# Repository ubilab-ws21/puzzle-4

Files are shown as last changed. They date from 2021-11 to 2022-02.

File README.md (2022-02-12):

# Team 4: Picture Puzzle #
We are building a puzzle in the Ubiquitous Computing Lab (UCL) aka Escape Room in WS21/22.
The Firmware folder contains all the Software code used for this project. 
In the Sequences folder are the created sequences as .mp4 and .pdf and also a solution file.
The Hardware folder contains most of the manuals and guides for the used hardware parts in our riddle for example the pin-assignment for the ESP32.

## Content #
* [Puzzle in Storyline](#1)
* [How the puzzle works](#2)
* [MQTT Documentation](#3)
* [Hardware](#4)
* [Project Timeline](#5)

## Puzzle in Storyline 
The players face a horrible situation because a solar storm happens while they visit a power supplier. This results in shutting down all electricity which is very dangerous because we are in the year 2050 and the blind trust in the technology is so big that this shutdown could be an apocalyptic scenario.
So the group needs to get access to the lab and server room and reboot the server with the control-software. In this way they can save our city by starting the electricity. 

Our picture puzzle starts after the team got acces to the lab and server room and solved the knock knock riddle to activate the server. So the server is working now but still secured by a code. To solve this puzzle the group needs to work as a team and under time pressure.
To stop unauthorized access the code can only be solved by people who work in the lab and know the enviroment. Another security mechanism is the need of more than one person similar to the two-man-mechanism from nuclear codes. One person always needs to stand at the server and press a button there while the others can walk freely in the room. The group needs to walk around and communicate with each other to solve it in time. 
After finding the solution and typing it into the server, they get access and the server reboots which results in saving our world. 

Accordingly the Escape Room is solved. 

## How the puzzle works
The puzzle starts by showing a text that the red button on the server needs to be pressed the whole time. After that a video sequence of picture cutouts included in a mathematical equation is shown. Simultanously there starts a text-to-speach which says that the server is locked and a password needs to be entered. The players need to find the corresponding picture from the cutout and take the number below into the equation to get one digit of the solution. There is a total of four equations with cutouts and therefore consists the solution of four digits.
After showing the four equations the sequence restarts as long as a predefined time. This predefined time depends on the amount of players. Two players get more time than four. Afterwards there will be a completely new sequence with other cutouts in other mathematical equations. Such a equation with a given cutout can be seen in the following picture:

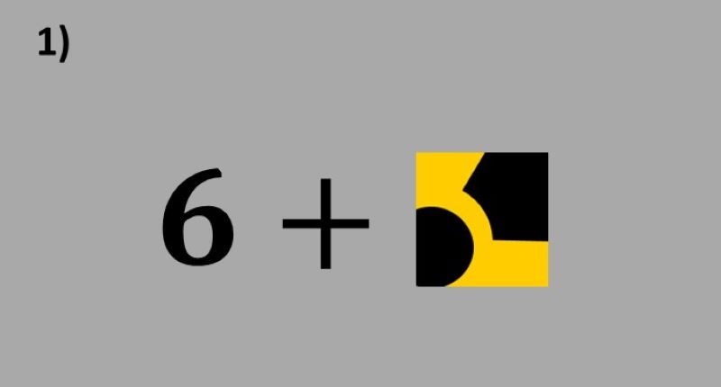
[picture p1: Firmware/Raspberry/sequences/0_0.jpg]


When seeing this on the server display the players should recognize this picture cutout from the rooms they played in before. Because in the entrance room and the lab room are many warning signs at the walls. An overview of all the warning signs can be seen in the next picture:



We placed them in pairs of two pictures at different walls in different rooms so the players have to use the whole space. Additionally we force the group to communicate with each other and benefit teamwork.
Under each picture will be a seven segment display and a button. The display only shows a number when the related button is pressed. To stop one person to stand in the middle of the room and look at the numbers under each picture. This can be seen in the next picture:

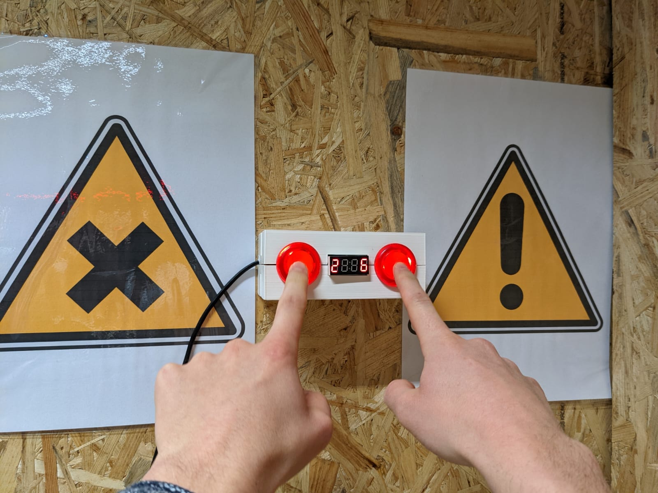
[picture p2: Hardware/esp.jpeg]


By finding the four pictures and the resulting four numbers and putting them in the equations the group should get a four digit code which they need to type in the server with a given numpad.
Overall does every picture pair consists of one ESP32, two buttons and four seven segment displays. The server consists of the numpad, Raspberry Pi and a display. Additionally there is an ESP32 with a seven-segment-display which represents the timer and a red button. The numpad, timer and red button can be seen in the next picture:

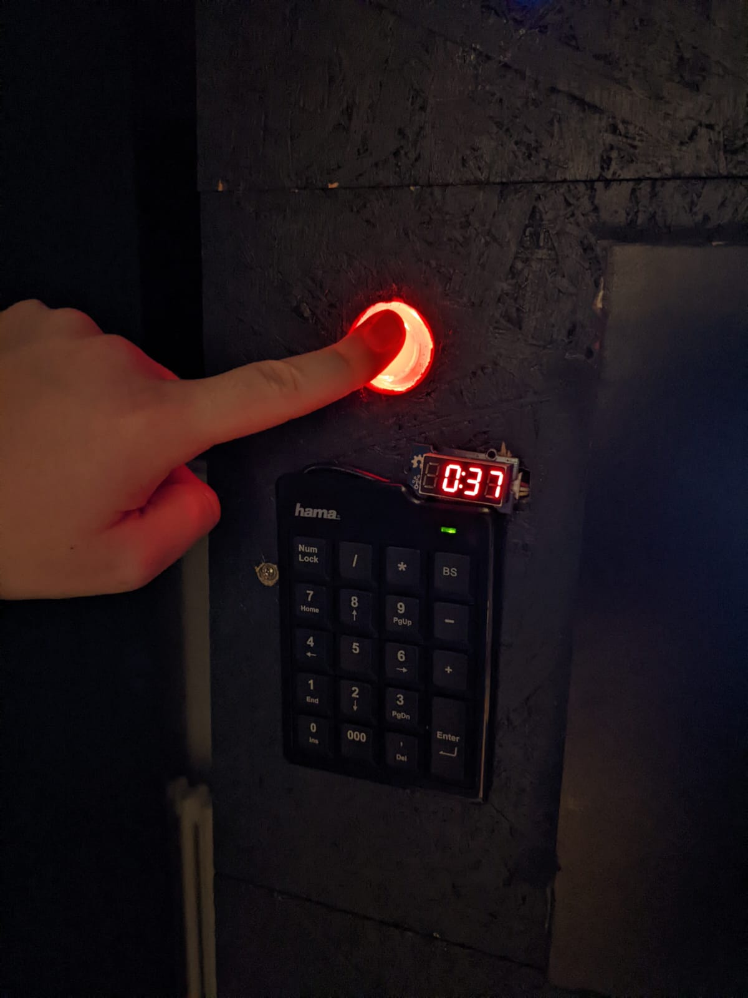
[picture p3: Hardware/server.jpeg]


All the ESP32 and the Raspberry Pi communicate via MQTT. Further MQTT informations can be found in the [MQTT Documentation](#3) or the [MQTT overview](https://github.com/ubilab-ws21/puzzle-4/tree/main/MQTT "MQTT overview").
At the beginning the Raspberry Pi is sending a retained message to the operator and AR hint system. After that it is waiting for the start message from the operator. When receiving this message the Raspi will send the starting sequence to the ESPs and starts with the first sequence. The ESP32 will power the buttons so they will light up and show the corresponding first number on the seven segment display when pressed. 
After some time has passed and the puzzle is not solved or the players enter a wrong code or the red button on the server dropped the Raspberry Pi sends a MQTT message at the text to speech to play a text to speech: "new sequence". So the players know that sequence has changed. Also the ESP32 receive a MQTT message from the Raspi that they need to change the numbers, a new sequence is shown on the display and the timer restarts. 
Therefore all numbers are saved in an array.

The following flow chart shows the overall course of events of our puzzle.

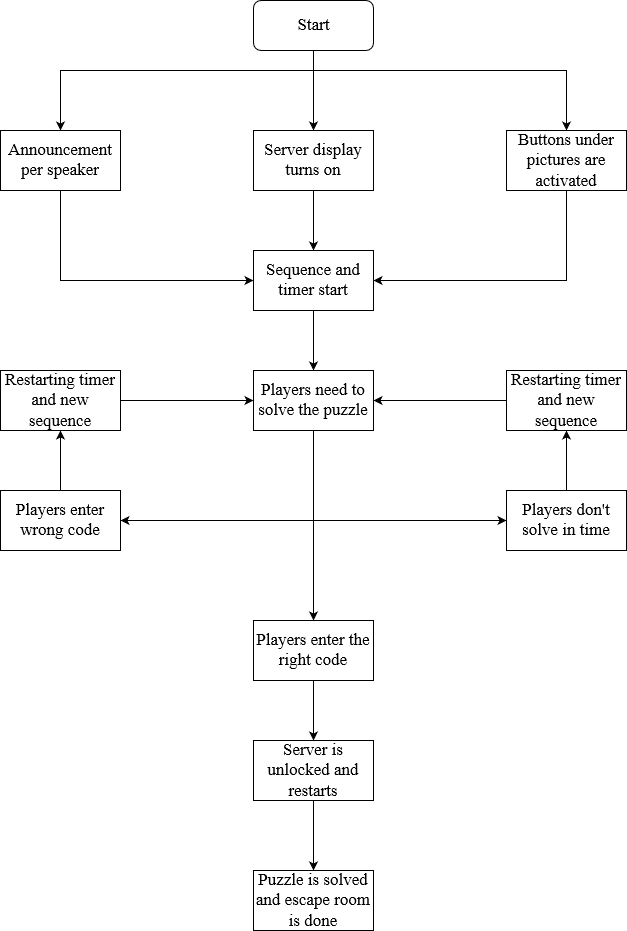
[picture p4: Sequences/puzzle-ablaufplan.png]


## MQTT Documentation 
In our communication design we distinguish between internal and external communication. The Raspi does everything external with the operator and hint system. The Raspi is sending and receiving informations from and to the individual ESPs. So all ESPs communicate internally with each other. A better overview for our MQTT communication and structure can be seen in the MQTT folder. There are also tables with the used topics and messages. 
[MQTT overview](https://github.com/ubilab-ws21/puzzle-4/tree/main/MQTT "MQTT overview")

## Hardware 
All documents and manuals needed to reconstruct this puzzle are in the "Hardware" folder.
The following picture gives on overview how the used hardware inside of the created case looks like:

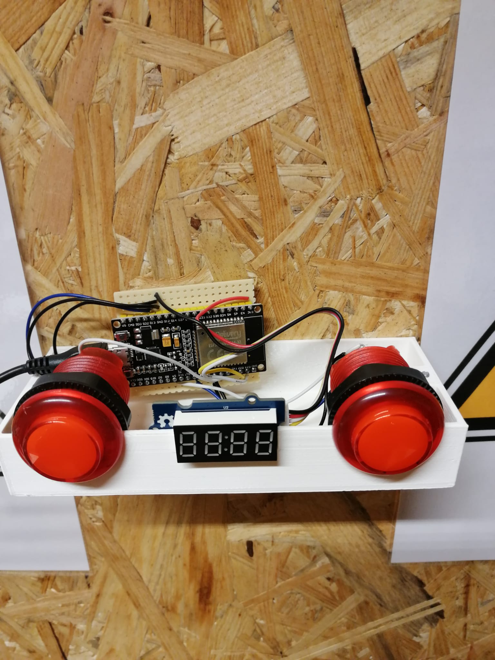
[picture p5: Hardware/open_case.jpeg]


## Project Timeline 
- [x] Concept finding for puzzle
- [x] Creating a BOM
- [x] Programming and testing OTA and MQTT with ESP32
- [x] Preparing warning signs and creating cutout sequences
- [x] First rough test run in the Escape room
- [x] Assembly of hardware for the under pictures buttons & 7-segment-displays
- [x] First software prototype for controlling the 7-segment-displays with arcade buttons
- [x] Soldering all parts together
- [x] Designing a 3D case in SolidWorks
- [x] Assembly of electronic with first case
- [x] Creating the GUI and Software for the Raspberry
- [x] Edit the 3D case and print the missing parts
- [x] Conception and creation of the timer 
- [x] Testing the network communication between the systems in the escape room
- [x] Assembly of the missing parts
- [x] Designing the final sequences for the riddle
- [x] Printing and foil-coating the pictures
- [x] Mount all parts in the room
- [x] Added progress bar after finishing the riddle
- [x] Implement extra button as dead-man switch
- [x] Fixed issues after integration run
- [x] Make use of AR hint system
- [x] Coordinate MQTT with operator
- [x] Provide power supply for all of them
- [x] Last testing and bug fixing
- [x] Finish documentation
- [x] Final run
- [x] very last bug fixes
- [x] Final run 2.0

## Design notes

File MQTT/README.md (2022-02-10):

### MQTT topics
| Topic | Description | Subscriber | Publisher |
| :--:	| :---: | :---: | :---:|
| 4/gamecontrol | general communication | operator, Raspi | operator, Raspi |
| op/gamecontrol | for the player amount | Raspi | operator |
| puzzle4/esp | messages for all 5 ESPs | ESP1-4 + Timer | Raspi |
| puzzle4/esp/timer | messages for Timer ESP | Timer ESP | Raspi |
| puzzle4/esp/timer/players | messages for Timer ESP | Timer ESP | Raspi |
| puzzle4/esp/sequence | messages for picture ESPs | ESP1-4 | Raspi |
| game/puzzle4 | AR hint system | Raspi, AR System | Raspi, AR System |

### MQTT commands
The following messages can be used to start or stop puzzle 4. These are send from the operator to the Raspi in "4/gamecontrol":
| method  | state  | data | | description |
|---|---|---|---|---|
| trigger | on | | | Starts the puzzle. |
| trigger | off | | | Restarts the puzzle and waits for a new 'trigger on'. |
| trigger | off | skipped | | Puzzle switches immediately into the solved state and waits for a 'trigger off' to restart. | 

The following messages are sent by the Raspi in "4/gamecontrol" to report the current status:

| method | state | data | | description |
|---|---|---|---|---|
| status | inactive | | | The Raspi has finished it's initialization and waits for a 'trigger on'. |
| status | active | | | The Raspi has received a 'trigger on' message and starts the puzzle. |
| status | solved | | | The picture puzzle is solved and waits for a 'trigger off'. |

### Chart of our MQTT communication


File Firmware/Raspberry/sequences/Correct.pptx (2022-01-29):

## Press and hold red button to start server boot process.

## Safety meassure: Keep pressing the button during bootup

## Server is starting up. Please enter Code on the next screen.

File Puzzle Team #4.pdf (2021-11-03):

# Puzzle Team #4

## Some puzzle ideas

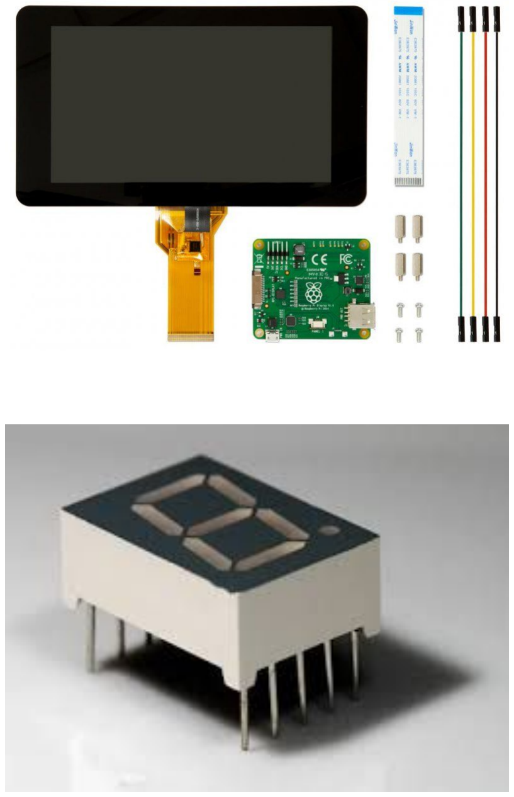
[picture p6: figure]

## Puzzle Idea #1: Warning-Sign-Puzzle

- General idea: Coop-puzzle
- One terminal in the room
- ideally in the server room: separate players → communication is needed
- 8-10 pictures distributed in both rooms
- maybe thematically matching warning signs
- under each picture is a 7-segment-display
- terminal shows parts of the pictures and an mathematical computation
- players have to search for the matching signs and solve the puzzle
- resulting in a 4-6 digit password to continue the escape room
- players are working under a time limit (e.g. 60-90s)

## Puzzle Idea #1: Warning-Sign-Puzzle

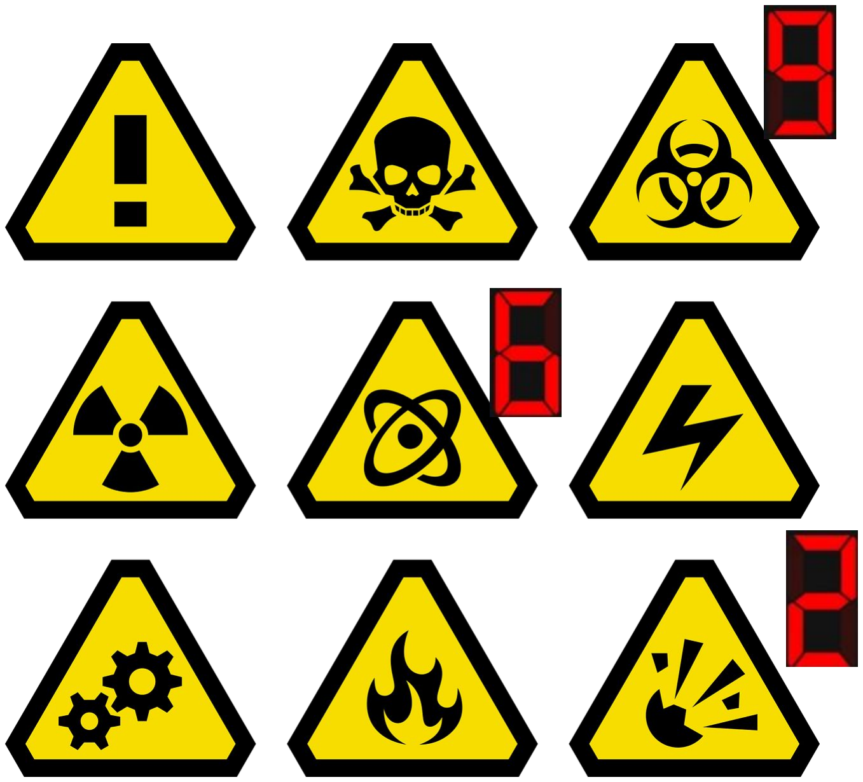
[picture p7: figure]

- Possible Sequence:
+3 | -2 | +1
- Resulting password: 5-7-7
- Players should fail on first attempt
- puzzle resets (numbers and sequence change)
- slowly learn the rules of the puzzle
- Time limit and difficulty in general are dependant on the number of players

## Puzzle Idea #2: Beamer

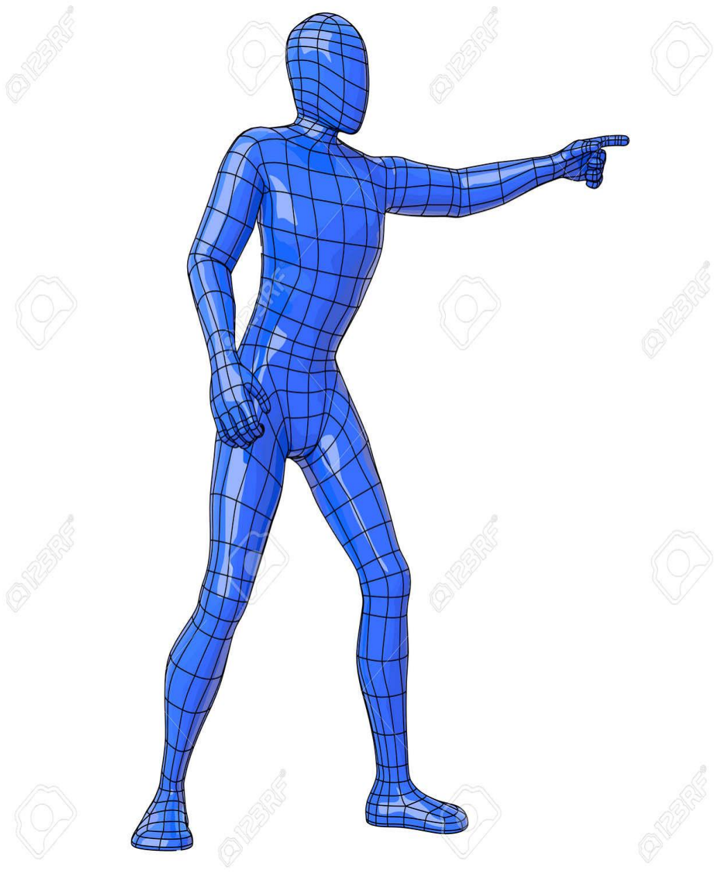
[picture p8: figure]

- after solving a puzzle, a beamer turns on and shows a blue screen on a wall
- there are multiple numbers on the wall but which number is the right one?
- players find one or more objects to put in front of the beamer
- fingers of the objects point to e.g. numbers on the wall
- players have to place the objects in an determined order
- resulting code opens something

## Puzzle Idea #3: Checkerboard

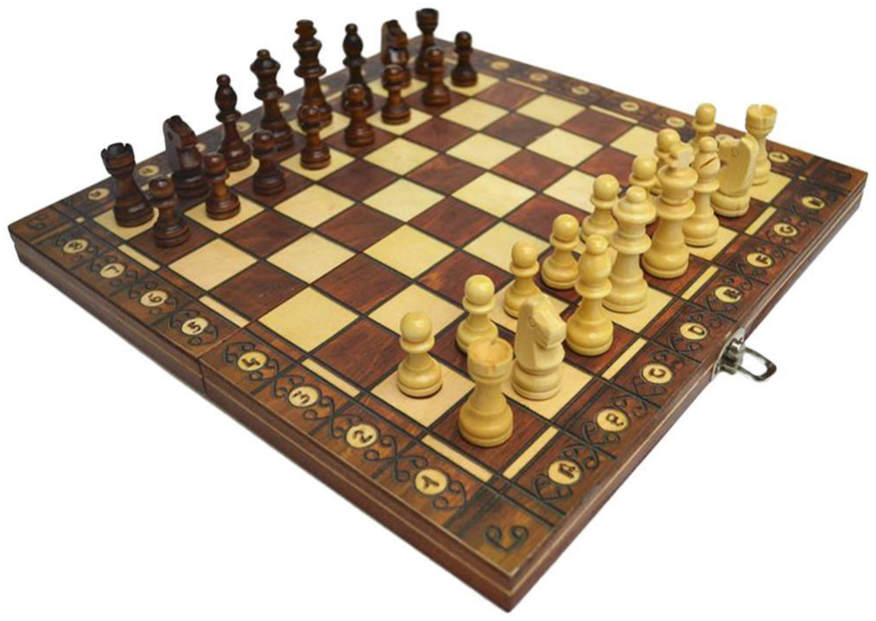
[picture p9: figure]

- players find a checkerboard with some figures standing on it
- can be glued to the board
- find another figure
- have to figure out the position that wins the game
- the figure has a small RFID chip in it
- by placing it on the correct position the next puzzle gets started
- not everyone knows the rules to chess
- players could find the moveset of the figures on a poster in the room
- or different game

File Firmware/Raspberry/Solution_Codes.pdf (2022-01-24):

## Escape Room Numbers

Sequenz | 0 | 1 | 2 | 3 | 4 | 5 | 6 | 7 | 8 | 9
Kreuz: | | 3 | | 6 | | 5 | | 7 | | 7
Ausrufezeichen: 3 | 6 | 3 | 7
Schneeflocke: | 4 | 5 | 2 | 6 | 4
Feuer: | 7 | 9 | 8 | 2 | 4 | 4
Blitz: | 3 | 2 | 1 | 2 | 5
Radioaktiv: | 1 | 4 | 9 | 8 | 7
Funk: | 2 | 1 | 3 | 8 | 6
Magnet: | 2 | 2 | 3 | 1 | 5

Sequenz0: 7 – 5 – 4 – 8

Sequenz1: 5 – 8 – 4 – 9

Sequenz2: 9 – 8 – 3 – 4

Sequenz3: 3 – 1 – 7 – 0

Sequenz4: 7 – 4 – 1 – 3

Sequenz5: 4 – 4 – 6 – 9

Sequenz6: 5 – 7 – 1 – 6

Sequenz7: 4 – 8 – 2 – 7

Sequenz8: 5 – 3 – 9 – 2

Sequenz9: 9 – 2 – 6 – 3

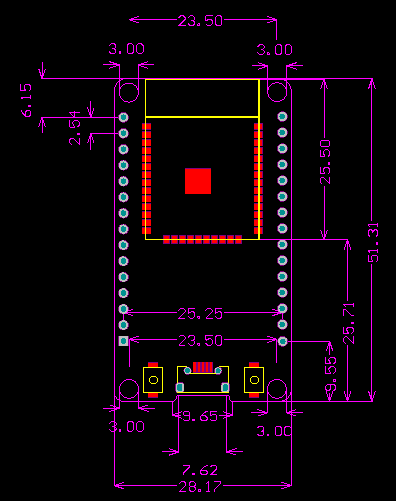
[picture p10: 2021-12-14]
Hardware/Case/SBC-NodeMCU-ESP32_dimensions.png

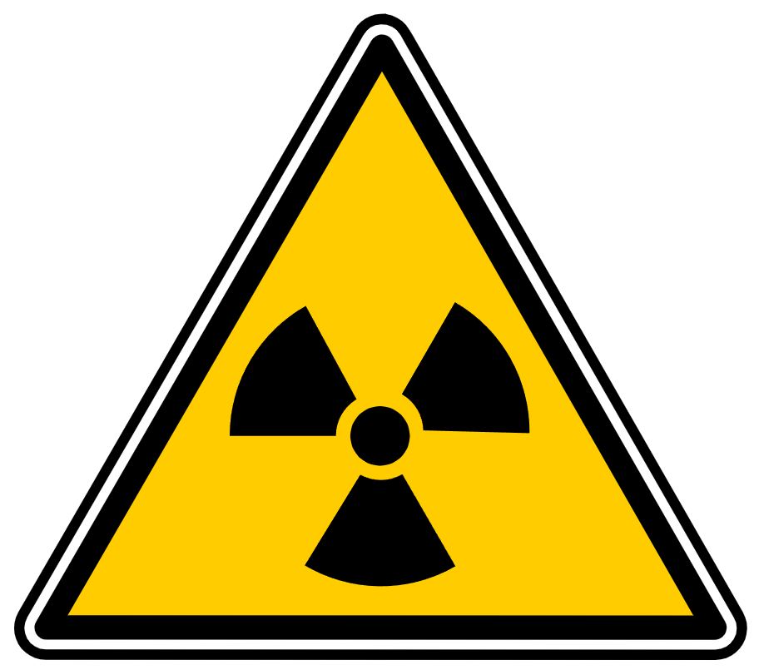
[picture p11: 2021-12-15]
Firmware/Raspberry/pictures/Radioaktiv.png

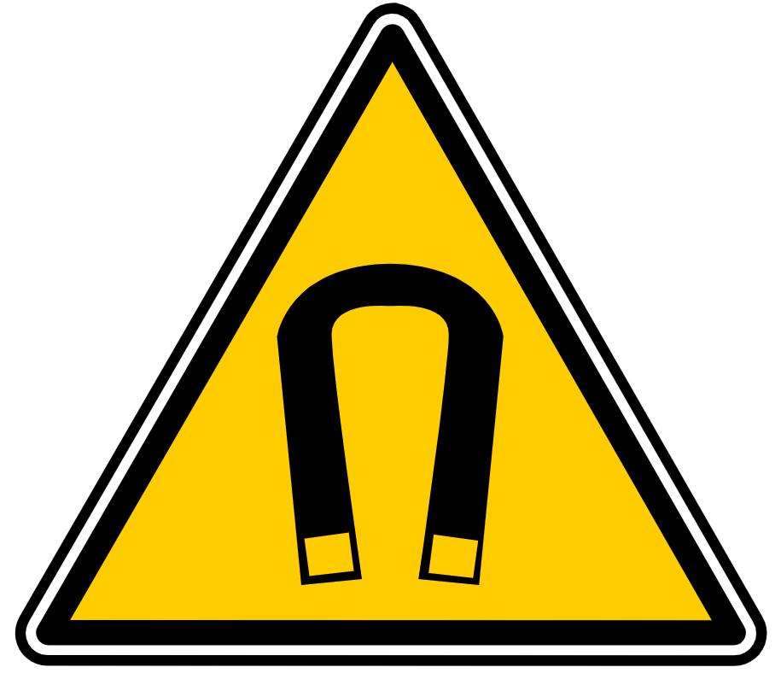
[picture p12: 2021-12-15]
Firmware/Raspberry/pictures/Magnet.png

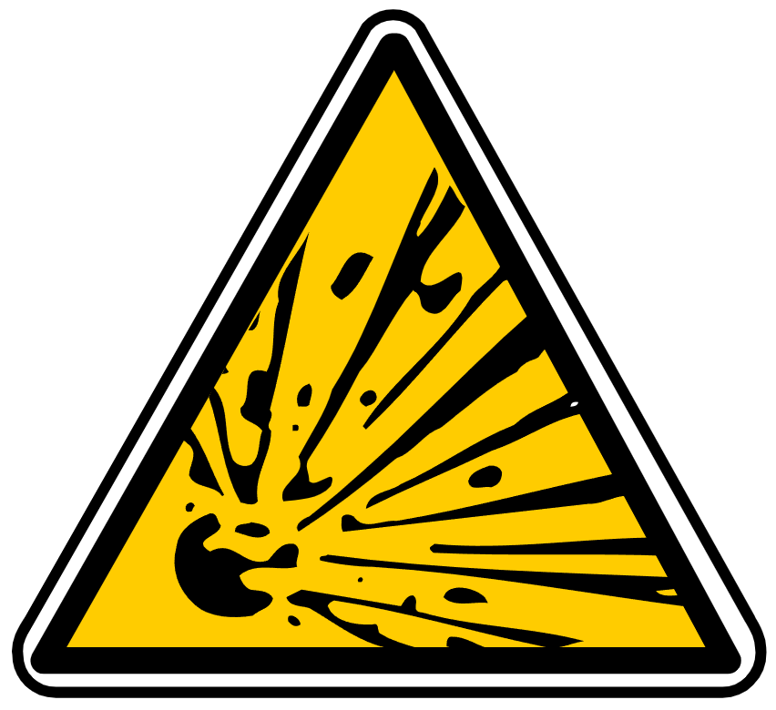
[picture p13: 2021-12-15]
Firmware/Raspberry/pictures/Explosion.png

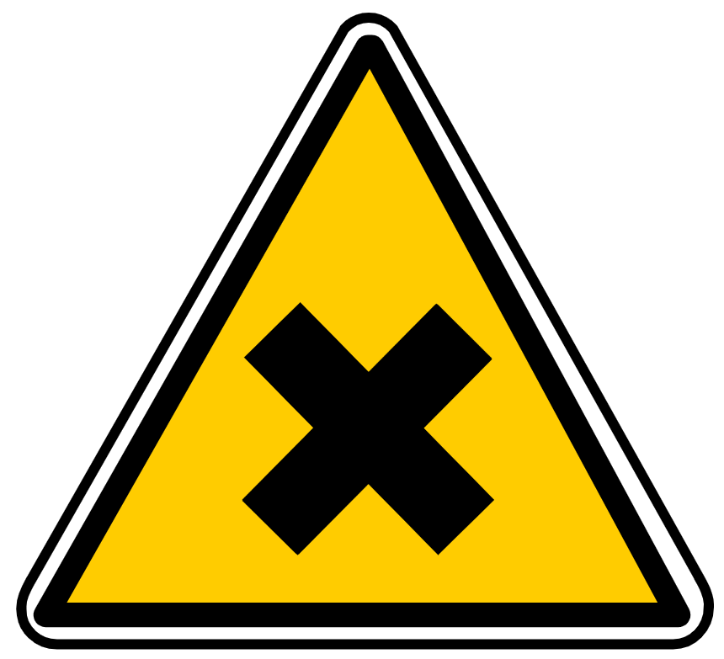
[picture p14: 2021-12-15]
Firmware/Raspberry/pictures/Kreuz.png

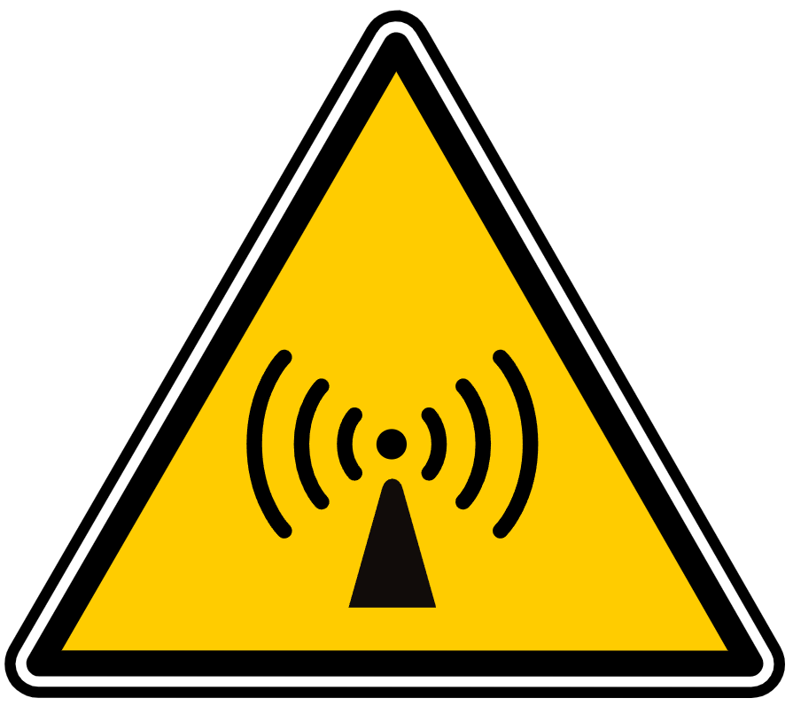
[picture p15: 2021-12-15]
Firmware/Raspberry/pictures/Funk.png

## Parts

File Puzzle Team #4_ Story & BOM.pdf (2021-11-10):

# Puzzle Team #4

## Story integration & BOM

## Recap

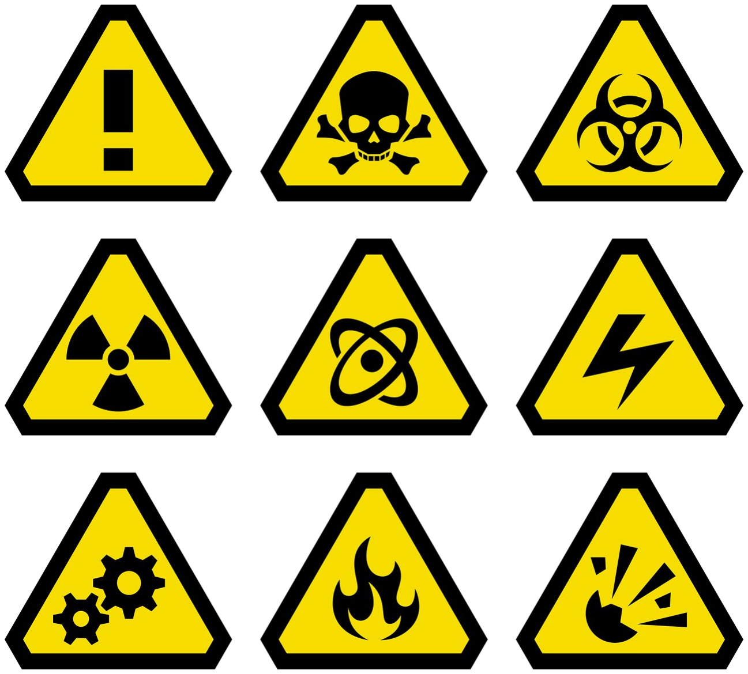
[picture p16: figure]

- Players see a sequence of picture cutouts and computations on the terminal
- one player needs to stay at the terminal
- other(s) have to find these pictures in the room
- | players are separated | have to work together to solve the
| puzzle
- pictures have a number underneath them
- by inserting these numbers into the sequence players receive a
| PIN
- buttons to activate LED-numbers and terminal

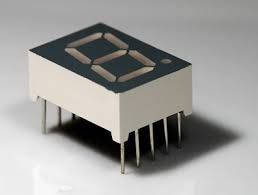
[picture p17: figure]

- Puzzle is very adjustable in length and difficulty
- whole picture vs. cutouts and time (10s vs 2min)

## Story adjustment

- General problem: Why are there puzzles in the control room of the company?

## Story adjustment

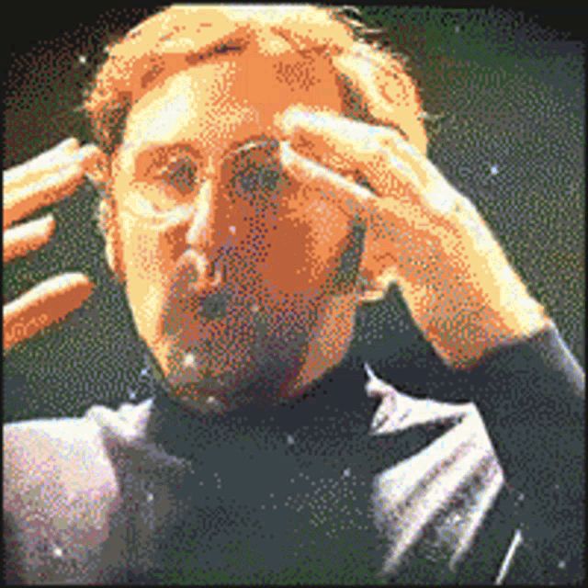
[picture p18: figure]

- General problem: Why are there puzzles in the control room of the company?
- Plot twist in the end: It was all a just a test for the new employees!
- this would explain all kinds of puzzles in the room
- all previous ideas can also work in this story (e.g. radio calls, etc.)
- instead of saving the world you just get a new job!

## Story integration

- Conditions: the server room is already opened
- therefore the puzzle takes place at the end of the escape room
- players have to use both rooms
- safety measures: at least two people needed to activate the server
- solve the puzzle to get access to/restart the server
- after that you can use the device (USB/floppy disc/futuristic device) to upload control-software back on server device was found earlier
- after successfully uploading the software the escape room is done

## BOM

- Raspberry PI + Display (Touchscreen or number pad)
- 8x Seven Digit Display
- 8x Buttons to activate Seven-Segment-Displays
- 8x LEDs to indicate that the buttons are active
- 8x ESP32 for each picture
- 8x Pictures (just print and laminate them?)
- maybe casings for each ESP and Seven-Segment-Display (3D-print)

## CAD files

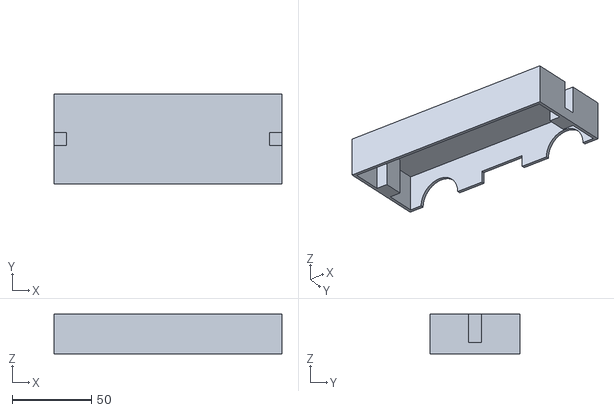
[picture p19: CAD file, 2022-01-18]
Hardware/Case/last_try v1.stl
144.0 x 57.0 x 25.0

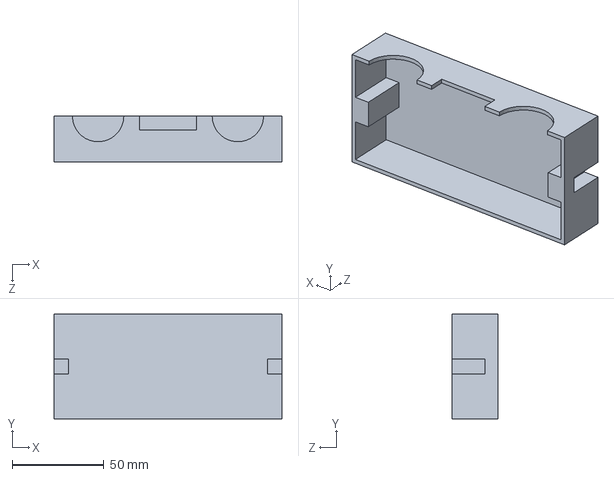
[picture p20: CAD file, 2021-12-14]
Hardware/Case/Teil1.SLDPRT
124.0 x 57.0 x 25.0 mm

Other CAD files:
Hardware/Case/last_try.SLDPRT
Hardware/Case/puzzle4_new.STL

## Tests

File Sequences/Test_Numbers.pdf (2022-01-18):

## Escape Room Numbers

Ausrufezeichen: 3

Biohackers: | 6
Blitz: | 8
Explosion: | 5
Feuer: | 7
Funk: | 6
Kreuz: | 2
Magnet: | 9
Radioaktiv: | 1
Schneeflocke: | 4

Sequenz1: 7 – 6 – 1 – 5

Sequenz2: 9 – 3 – 2 – 4

Sequenz3: 3 – 7 – 5 – 8

Sequenz4: 7 – 5 – 4 – 8

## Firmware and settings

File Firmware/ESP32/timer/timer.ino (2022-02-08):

/*
 * This is the Firmware for a ESP32 to control a TM1637 7-segment-display which is used as a timer.
 * It shows how much time is still left to solve the current attempt of the puzzle. 
 * If the puzzle is not solved the timer will reset and starts the countdown again.
 */

 /*
 * MQTT topics:
 * puzzle4/esp [start, stop] - control the state of all ESPs
 * puzzle4/esp/timer [error, restart, solved] - error:   timer is either over or the entered passwort is wrong
 *                                            - restart: timer gets restarted again
 *                                            - solved:  puzzle is solved and the timer stops
 * puzzle4/esp/timer/players [int] - set the number of players to influence puzzle timer 2  -> 1:07
 *                                                                                       3  -> 0:57
 *                                                                                       4+ -> 0:47
 * puzzle4/esp/timer/button [on, off] - sets button state                                                                                    
 */
 
#include <WiFi.h>
#include <ESPmDNS.h>
#include <ArduinoOTA.h>
#include <PubSubClient.h>
#include "TM1637.h"

#define SERIALSPEED 115200

// use WiFi and MQTT
#define networkCapabilities

// Wifi Credentials
#define SSID "ubilab_wifi" //ubilab_wifi
#define PWD "ohg4xah3oufohreiPe7e"  // ohg4xah3oufohreiPe7e

//MQTT Credentials
#define MQTT_SERVER_IP "10.8.166.20" //10.8.166.20
#define MQTT_PORT 1883
#define MAX_MSG 50
char msg[MAX_MSG] = {'\0'};

#define NAME "Puzzle4-Timer"     //Name of ESP
#define OTA_PWD "pictures"      // OTA Password

//pin definition for TM1637
#define CLK 22  // clock
#define DIO 23  // data
TM1637 tm1637(CLK,DIO);

//pins for arcade button
#define LED 13
#define BUTTON 19

// timer variables
int timer2[] = {1, 0, 7};  //timer for 2  players 1:07 min
int timer3[] = {0, 5, 7};  //timer for 3  players 0:57 min
int timer4[] = {0, 4, 7};  //timer for 4+ players 0:47 min


int timer[] = {0, 5, 7};  // default to 0:57 min
int position_minute = timer[0];
int high_position_second = timer[1];
int low_position_second = timer[2];

// timestep variables
int myTime = 0;
int timestep = 1000; 

// variables
bool reset = false;
bool blinks = false;
bool mqttStart = false;
bool puzzle_solved = false;
bool button_light = false;
bool button_press = false;
int number_of_players = 0;

WiFiClient mqttClient;
PubSubClient mqtt(mqttClient);

void setup() {
  Serial.begin(SERIALSPEED);

  #ifdef networkCapabilities
    WiFi.begin(SSID,PWD);
    Serial.print("Connecting to ");
    Serial.println(SSID);
  
    WiFi.setHostname(NAME);
    
    // wait for connecting
    while (WiFi.status() != WL_CONNECTED) {
      delay(500); Serial.print(".");
    } 
    // Print IP
    Serial.println("\nWiFi connected.\nIP Adress: ");
    Serial.println(WiFi.localIP());
  
    // Setting up mDNS
    if (!MDNS.begin(NAME)) { 
      Serial.println("Error setting up MDNS responder!");
    }
    MDNS.addService("_escape", "_tcp", 2000);
  
    mqtt.setServer(MQTT_SERVER_IP, MQTT_PORT);
    // MQTT connect
    if (mqtt.connect(NAME)) {
      Serial.println("Connected to MQTT server");
    } else {
      Serial.println("Cannot connect to MQTT server");
    }
    mqtt.setCallback(mqttCallback);

    mqtt.subscribe("puzzle4/esp");
    mqtt.subscribe("puzzle4/esp/timer");
    mqtt.subscribe("puzzle4/esp/timer/players");
    mqtt.subscribe("puzzle4/esp/timer/button");

    // Arduino OTA
    ArduinoOTA.setHostname(NAME);
    ArduinoOTA.setPassword(OTA_PWD);
    ArduinoOTA.onStart([]() {
    Serial.println("Start updating");
    });
    ArduinoOTA.onEnd([]() {
    Serial.println("Finished updating");
    });
    ArduinoOTA.onError([](ota_error_t error) {
    Serial.println("Error updating");
    ESP.restart();
    });
    ArduinoOTA.begin();
  #endif

  // 7-segment display setup
  tm1637.init();
  tm1637.set(4);  // Bright-level from 0 to 7

  tm1637.clearDisplay();

  //button and button light
  pinMode(LED, OUTPUT);
  pinMode(BUTTON, INPUT_PULLUP);
  
}

void loop() {
  #ifdef networkCapabilities
    ArduinoOTA.handle();
  
    mqtt.loop();

    while(!mqttStart){
      //allow changing button light before start mqtt message
      if (button_light == true) {
        digitalWrite(LED, HIGH);
      } else if (button_light == false) {
        digitalWrite(LED, LOW);
      }

      //check button state before start mqtt message
      if (digitalRead(BUTTON) == 0) {
        if (button_press == false) {
          button_press = true;
          mqtt.publish("puzzle4/button", "true");
        }
      } else {
        if (button_press == true) {
          button_press = false;
          mqtt.publish("puzzle4/button", "false");
        }
      }
      //wait for MQTT reconnect if signal is lost
      if (!mqtt.connected()){
        Serial.println("Client disconnected!");
        reconnect();
        mqtt.loop();
      }
      //Serial.println("Waiting for start signal over MQTT");
      mqtt.loop();
    }
  #endif

  //light up button when mqtt message arrives
  if (button_light == true) {
    digitalWrite(LED, HIGH);
  } else if (button_light == false) {
    digitalWrite(LED, LOW);
  }

  //check for button state
  if (digitalRead(BUTTON) == 0) {
    if (button_press == false) {
      button_press = true;
      mqtt.publish("puzzle4/button", "true");
    }
  } else {
    if (button_press == true) {
      button_press = false;
      mqtt.publish("puzzle4/button", "false");
    }
  }

  if (!reset and !puzzle_solved) {
    // enter every second if reset is false
    if(millis() >= myTime + timestep) {
      myTime = millis();

      // stop timer
      if (high_position_second == 0 and low_position_second == 0 and position_minute == 0) {
        reset = true;
      }
      // change to lower minute f.ex. 2:00 -> 1:59
      else if (high_position_second == 0 and low_position_second == 0 and position_minute !=0) {
        position_minute--;
        high_position_second = 5;
        low_position_second = 9;      
      }

      //change to lower deci-second  f.ex. 2:30 -> 2:29
      else if (high_position_second != 0 and low_position_second == 0) {
        high_position_second--;
        low_position_second = 9;
      }

      //normal case, count a second down  f.ex. 2:35 -> 2:34
      else {
        low_position_second--;
      }
    }    
  }

  if (reset or puzzle_solved) {
    blinks = true;
    if (millis() >= myTime + timestep/2) {
      myTime = millis();
      tm1637.point(true);
      tm1637.display(1, position_minute);
      tm1637.display(2, high_position_second);
      tm1637.display(3, low_position_second);
    } else if ((millis() >= myTime + timestep/4)) {
      tm1637.point(false);
      tm1637.clearDisplay();
    }
  }

  if (!blinks) {
    tm1637.display(1, position_minute);
    tm1637.display(2, high_position_second);
    tm1637.display(3, low_position_second);
    tm1637.point(true);
  }

  if (!mqtt.connected()){
    Serial.println("Client disconnected!");
    reconnect();
    mqtt.loop();
  }
}

// MQTT Callback function
void mqttCallback(char* topic, byte* message, unsigned int length) {
  // Convert to cstring
  int len = min((int)length, (int)(MAX_MSG-1));
  memcpy(&msg[0], message, len);
  msg[len] = '\0'; 

  Serial.printf("MQTT msg on topic: %s: %s\n", topic, &msg);

  analyzeMQTTMessage(topic, msg);
}

void analyzeMQTTMessage(char* topic, char* msg) {
  // check for start-message
  if(strcmp(topic, "puzzle4/esp") == 0 and strcmp(msg, "start") == 0) {
    mqttStart = true;
    blinks = false;
    puzzle_solved = false;
    reset = false;
    position_minute = timer[0];
    high_position_second = timer[1];
    low_position_second = timer[2];
  }

  // check for end-message
  if(strcmp(topic, "puzzle4/esp") == 0 and strcmp(msg, "stop") == 0) {
    tm1637.point(false);
    tm1637.clearDisplay();
    mqttStart = false;
    blinks = false;
    puzzle_solved = false;
    position_minute = timer[0];
    high_position_second = timer[1];
    low_position_second = timer[2];
  }

  // check for number of players to choose the time for the puzzle
  if(strcmp(topic, "puzzle4/esp/timer/players") == 0) {
    sscanf(msg, "%d", &number_of_players);
    // 1-2 players: puzzle time = 1:07
    if (number_of_players < 3) {
      timer[0] = 1;
      timer[1] = 0;
      timer[2] = 7;
      position_minute = timer[0];
      high_position_second = timer[1];
      low_position_second = timer[2];     
    }
    // 3 players: puzzle time = 0:57
    if (number_of_players == 3) {
      timer[0] = 0;
      timer[1] = 5;
      timer[2] = 7;
      position_minute = timer[0];
      high_position_second = timer[1];
      low_position_second = timer[2];    
    }
    // 4+ players: puzzle time = 0:47
    if (number_of_players > 3) {
      timer[0] = 0;
      timer[1] = 4;
      timer[2] = 7;
      position_minute = timer[0];
      high_position_second = timer[1];
      low_position_second = timer[2];      
    }
  }

  // check for reset
  if(strcmp(topic, "puzzle4/esp/timer") == 0 and strcmp(msg, "error") == 0) {
    reset = true;
  }

  // check for restart
  if(strcmp(topic, "puzzle4/esp/timer") == 0 and strcmp(msg, "restart") == 0) {
    reset = false;
    blinks = false;
    position_minute = timer[0];
    high_position_second = timer[1];
    low_position_second = timer[2];
  }

  // check for solved
  if(strcmp(topic, "puzzle4/esp/timer") == 0 and strcmp(msg, "solved") == 0) {
    puzzle_solved = true;
    timer[0] = 0;
    timer[1] = 5;
    timer[2] = 7;
    Serial.println("Puzzle solved!!");
  }

  //check if button should be turned on
  if(strcmp(topic, "puzzle4/esp/timer/button") == 0 and strcmp(msg, "on") == 0) {
    button_light = true;
    Serial.println("Button light turned on");
  }
  
  if(strcmp(topic, "puzzle4/esp/timer/button") == 0 and strcmp(msg, "off") == 0) {
    button_light = false;
    Serial.println("Button light turned off");
  }
}

void reconnect() { 
  while (!mqtt.connected()) {  
    if (mqtt.connect(NAME)) { 
      Serial.println("MQTT connected");        
      mqtt.setCallback(mqttCallback);
      mqtt.subscribe("puzzle4/esp");
      mqtt.subscribe("puzzle4/esp/sequence");  
    } 
  }    
}

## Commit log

2021-12-01 Add files via upload
    integration of button and display
    readout of mqtt message currently not working
    [puzzle4-pictures.ino]
2021-12-01 Add files via upload
    Integration of Button and 7-Segment-Display
    Readout of mqtt messages currently not working
    [puzzle4-pictures.ino]
2021-12-04 Revert "Added MQTT message processing and start/stop capabilities"
    [puzzle4-pictures.ino]
2021-12-04 Added MQTT message processing and start/stop capabilities
    Program now waits for first start message over MQTT and then turns the LEDs on.
    Number on the display can be adjusted using MQTT message.
    Programm can be stopped with stop message and the LEDs turn off.
2021-12-08 Inital commit for program running on the raspberry
    Implements basic MQTT capabilities for the Raspberry.
    Program establishes MQTT-connection and sends the start command to the ESPs. Sends a new number to display after each second.
2021-12-14 3D skizze
    [Teil1.SLDPRT, Teil1.STL]
2022-01-12 Added 2nd interation of the GUI
    Added image, text entry field and enter button.
2022-01-13 added new 3D model for the case
    [puzzle4_new.SLDPRT, puzzle4_new.STL]
2022-01-16 Create timer.ino
    first implementation of timer
    mqtt integration is already working
2022-01-16 Update timer.ino
    ...
2022-01-18 added new 3D model
    [last_try v1.stl, last_try.SLDPRT]
2022-01-19 Updated program for the Raspberry
    Nearly completed the GUI with MQTT and program sequence.
    Still missing: Reset the whole program on MQTT reset from operator
2022-01-20 Firmware update
    Firmware for pictures and timer updated
    MQTT topics coordinated to rasperry pi
2022-01-22 Made same adjustments to Raspberry program
2022-01-25 Finished Raspberry Code
    Added option to choose between our puzzle and the puzzle from the last escape room. Also implemented that the display automatically turns on, when puzzle is started. Program now listens for stop mess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
2022-01-27 Bugfixes for Raspberry program
2022-01-28 Added button detection to ESP with timer functionality
    Timer can now detect weather a button is pressed or not. State is published using MQTT and button light can alos be controlled over MQTT
2022-01-29 Finished implementation of the control button
    It is now always necessary to press a red button to start up the server.
    Also added a progress bar for visualizing the boot up process.
2022-02-03 Updated timer
    bug fix
    [timer.ino]
2022-02-08 Fixed remaining reconnect issues of the ESPs
    [puzzle4-pictures.ino, timer.ino]
